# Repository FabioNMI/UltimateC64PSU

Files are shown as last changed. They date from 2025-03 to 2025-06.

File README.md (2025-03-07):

Welcome to the Ultimate Commodore 64 Power Supply!

This circuit is designed to power a Commodore 64 computer without the use of bulky transformers and by generating pseudo-AC (9Vrms) and 5Vdc to power the machine.

Please use it at your own risk, there are no guarantees that this circuit is safe as it is not certified in any way!

Link to the video in the NMI channel: https://youtu.be/_GyQUuKDc-I

There are two version that differ only in the PCB form-factor:

v7_front is the format featured in my video (power output in the front)

v8_back is a different layout with all connections on the back

Enjoy!

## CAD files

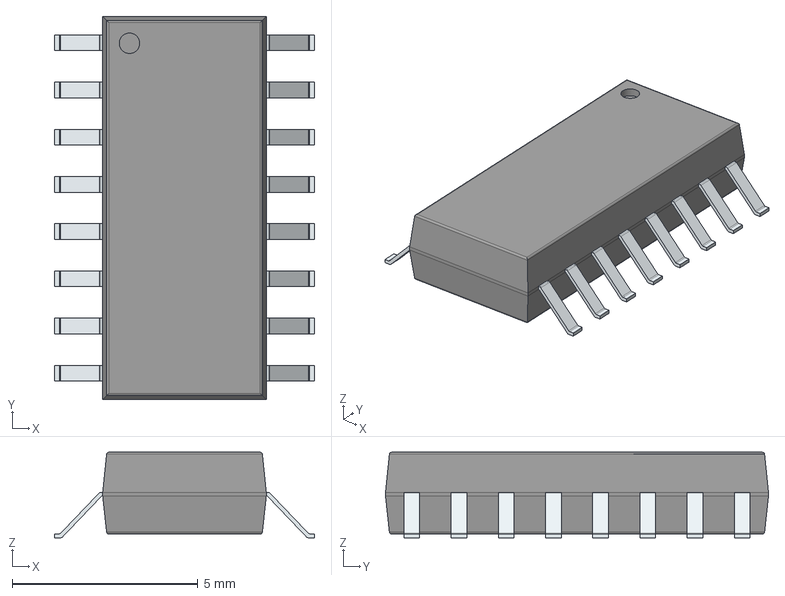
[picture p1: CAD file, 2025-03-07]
v7_front/LIB_PS2801C-4-F3-A/PS2801C-4-F3-A/3D/PS2801C-4-F3-A.stp
7.00 x 10.3 x 2.30 mm
PinsArrayLR

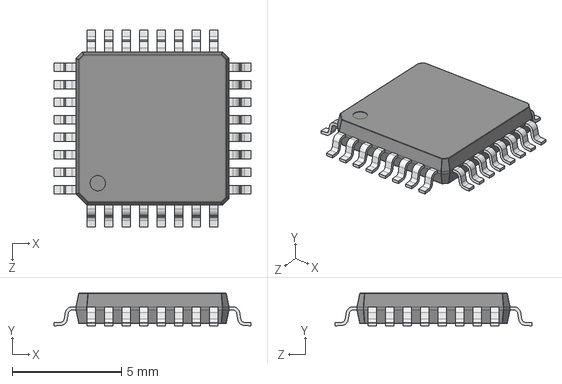
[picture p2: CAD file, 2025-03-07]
v7_front/LIB_R7FA0E1073CFJ#AA0/R7FA0E1073CFJ#AA0/3D/R7FA0E1073CFJ#AA0.stp
9.00 x 1.50 x 9.00 mm

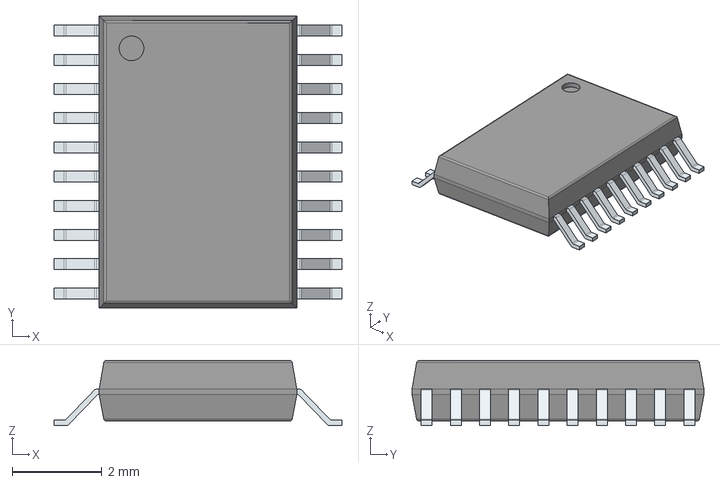
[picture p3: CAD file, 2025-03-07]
v7_front/LIB_R7FA0E1073CSC#CA0/R7FA0E1073CSC#CA0/3D/R7FA0E1073CSC#CA0.stp
6.40 x 6.50 x 1.45 mm
PinsArrayLR

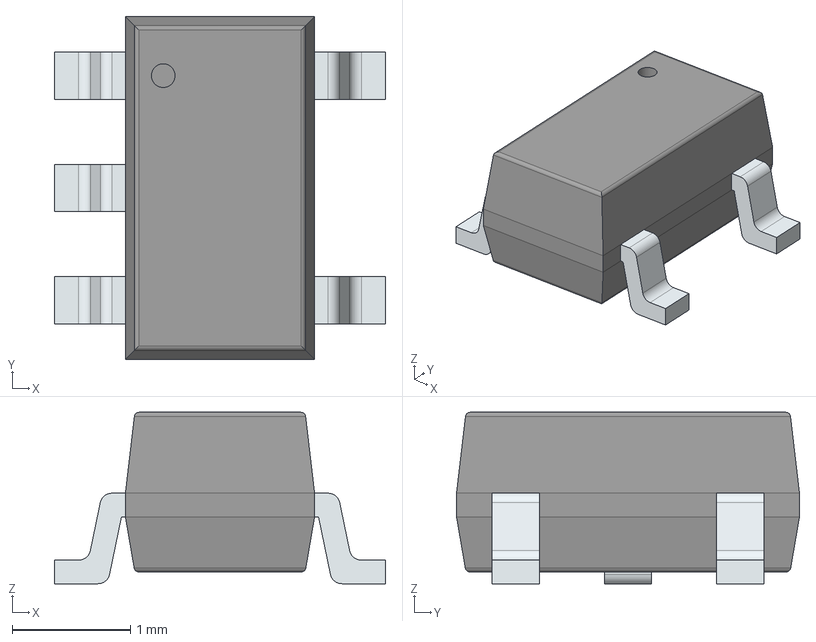
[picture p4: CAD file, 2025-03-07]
v7_front/LIB_ISL28005FH20Z-T7/ISL28005FH20Z-T7/3D/ISL28005FH20Z-T7.stp
2.80 x 2.90 x 1.45 mm
PinsArrayL
PinsArrayR

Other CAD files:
v7_front/LIB_ISL28005FH20Z-T7/ISL28005FH20Z-T7/Allegro/sot95p280x145-5n.psm
v7_front/LIB_ISL28005FH20Z-T7/ISL28005FH20Z-T7/DEHDL/isl28005fh20z_t7/chips/chips.prt
v7_front/LIB_PS2801C-4-F3-A/PS2801C-4-F3-A/Allegro/soic127p700x230-16n.psm
v7_front/LIB_PS2801C-4-F3-A/PS2801C-4-F3-A/DEHDL/ps2801c_4_f3_a/chips/chips.prt
v7_front/LIB_R7FA0E1073CFJ#AA0/R7FA0E1073CFJ#AA0/Allegro/qfp80p900x900x170-32n.psm
v7_front/LIB_R7FA0E1073CFJ#AA0/R7FA0E1073CFJ#AA0/DEHDL/r7fa0e1073cfj#aa0/chips/chips.prt
v7_front/LIB_R7FA0E1073CSC#CA0/R7FA0E1073CSC#CA0/Allegro/sop65p640x145-20n.psm
v7_front/LIB_R7FA0E1073CSC#CA0/R7FA0E1073CSC#CA0/DEHDL/r7fa0e1073csc#ca0/chips/chips.prt
v8_back/LIB_ISL28005FH20Z-T7/ISL28005FH20Z-T7/Allegro/sot95p280x145-5n.psm
v8_back/LIB_ISL28005FH20Z-T7/ISL28005FH20Z-T7/DEHDL/isl28005fh20z_t7/chips/chips.prt
v8_back/LIB_PS2801C-4-F3-A/PS2801C-4-F3-A/Allegro/soic127p700x230-16n.psm
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

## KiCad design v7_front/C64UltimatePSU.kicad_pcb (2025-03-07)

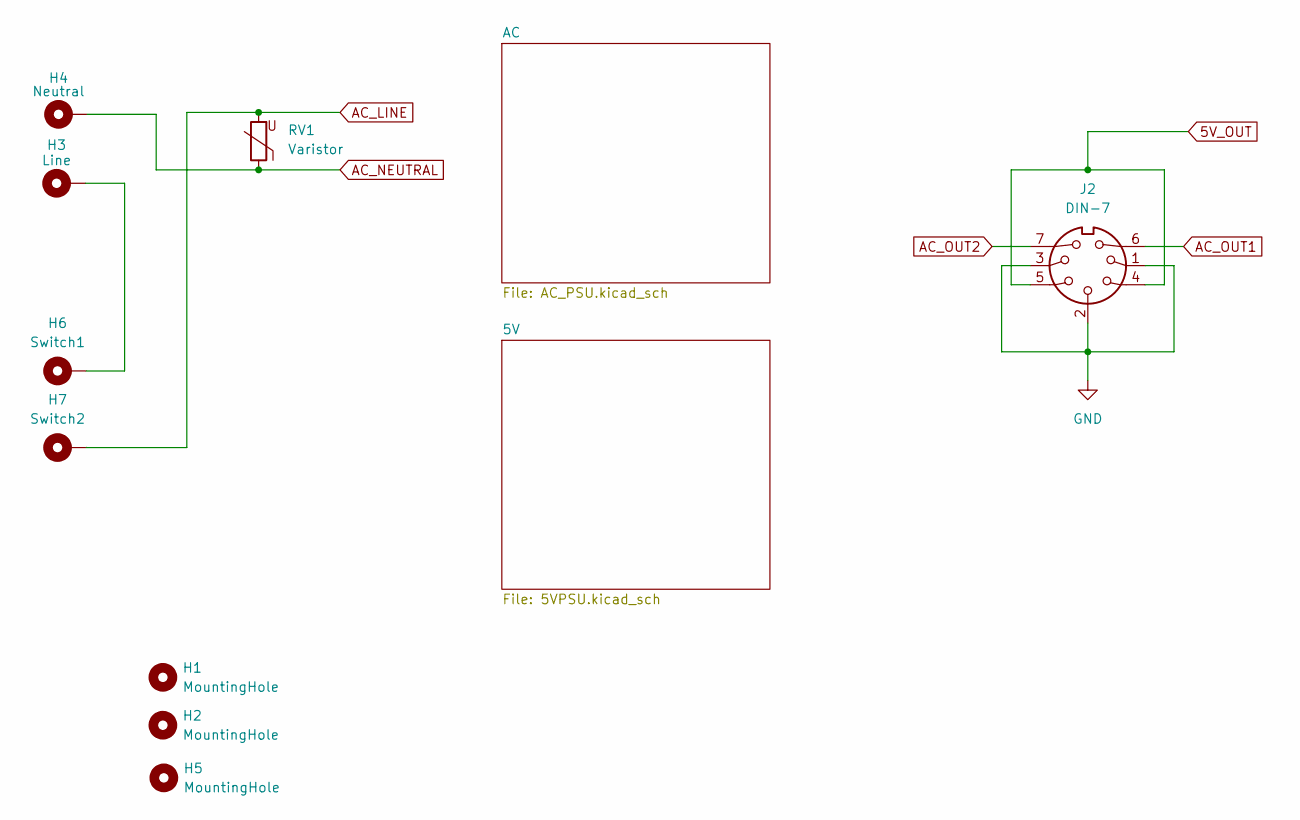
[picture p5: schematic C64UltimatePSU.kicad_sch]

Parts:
H1, H2, H5: MountingHole; MountingHole_3.5mm
H3: Line; MountingHole_2.5mm_Pad
H4: Neutral; MountingHole_2.5mm_Pad
H6: Switch1; MountingHole_2.5mm_Pad
H7: Switch2; MountingHole_2.5mm_Pad
J2: DIN-7; POWER_CON_DIN7
RV1: Varistor; RV_Disc_D7mm_W4mm_P5mm

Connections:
5V_OUT: J2.4, J2.5; also elsewhere on the board
AC_LINE: H7.1, RV1.2; also elsewhere on the board
AC_NEUTRAL: H4.1, RV1.1; also elsewhere on the board
AC_OUT1: J2.6; also elsewhere on the board
AC_OUT2: J2.7; also elsewhere on the board
GND: J2.1, J2.2, J2.3; also elsewhere on the board
unnamed: H3.1, H6.1

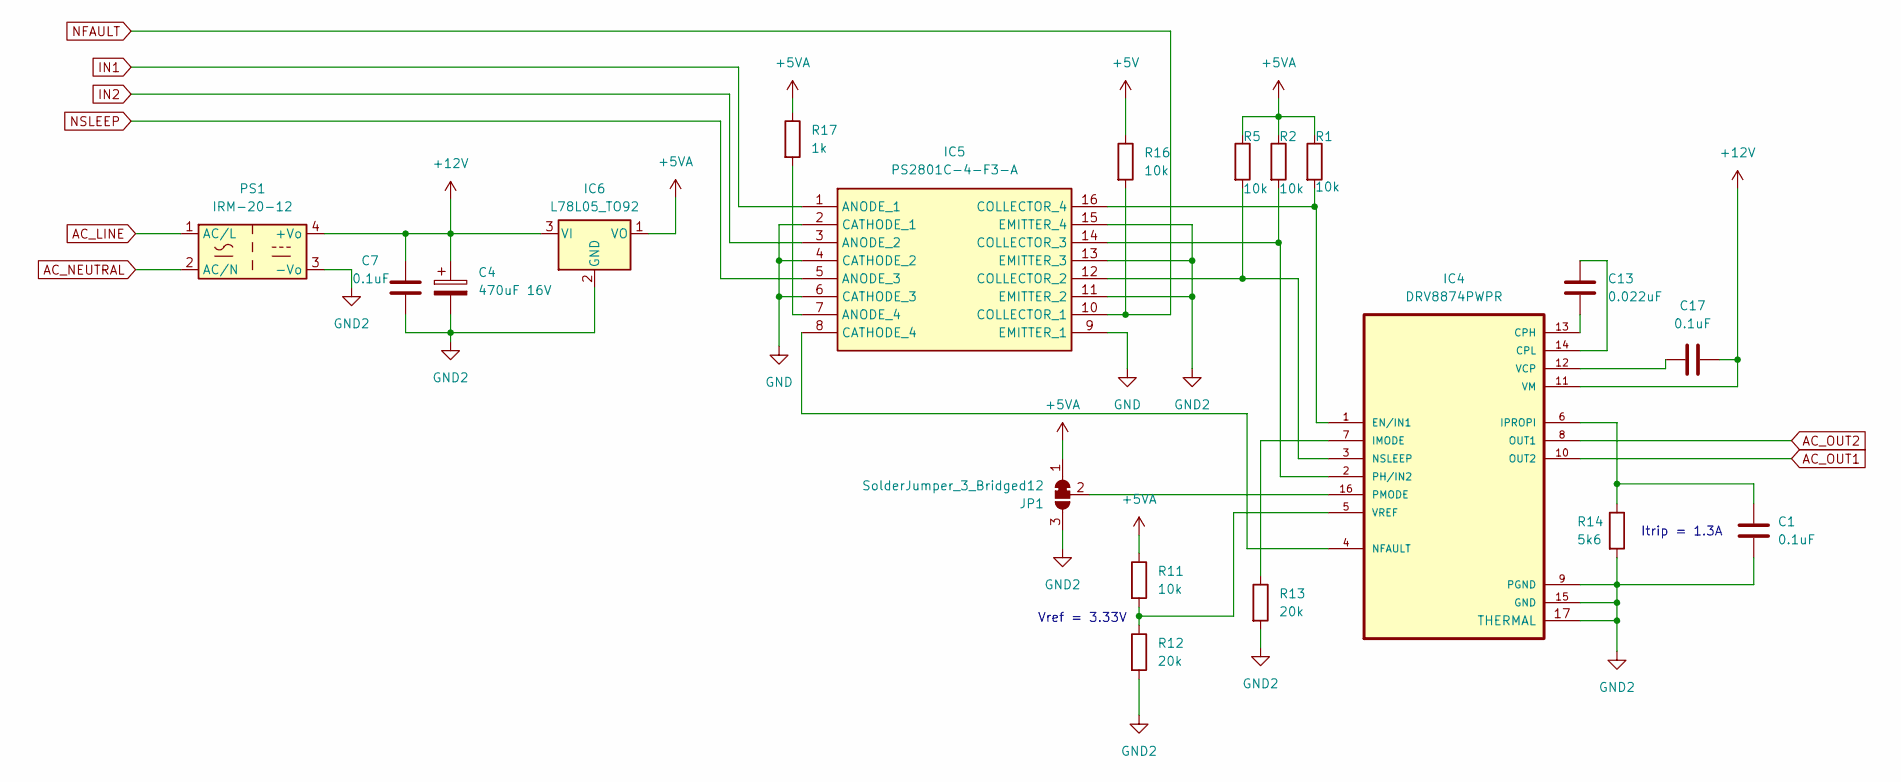
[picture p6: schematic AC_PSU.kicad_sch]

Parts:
C1, C7, C17: 0.1uF; C_0805_2012Metric_Pad1.18x1.45mm_HandSolder
C4: 470uF 16V; CP_Radial_D6.3mm_P2.50mm
C13: 0.022uF; C_0805_2012Metric_Pad1.18x1.45mm_HandSolder
IC4: DRV8874PWPR; SOP65P640X120-17N
IC5: PS2801C-4-F3-A; SOIC-16_4.55x10.3mm_P1.27mm; Manufacturer_Part_Number PS2801C-4-F3-A
IC6: L78L05_TO92; TO-92_Inline
JP1: SolderJumper_3_Bridged12; SolderJumper-3_P1.3mm_Bridged12_Pad1.0x1.5mm_NumberLabels
PS1: IRM-20-12; Converter_ACDC_MeanWell_IRM-20-xx_THT
R1, R2, R5, R11, R16: 10k; R_0805_2012Metric_Pad1.20x1.40mm_HandSolder
R12, R13: 20k; R_0805_2012Metric_Pad1.20x1.40mm_HandSolder
R14: 5k6; R_0805_2012Metric_Pad1.20x1.40mm_HandSolder
R17: 1k; R_0805_2012Metric_Pad1.20x1.40mm_HandSolder

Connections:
+5V: R16.1; also elsewhere on the board
+5VA: IC6.1 (VO), JP1.1 (A), R1.1, R2.1, R5.1, R11.1, R17.1
+12V: C4.1, C7.2, C17.2, IC4.11 (VM), IC6.3 (VI), PS1.4 (+Vo)
AC_LINE: PS1.1 (AC/L); also elsewhere on the board
AC_NEUTRAL: PS1.2 (AC/N); also elsewhere on the board
AC_OUT1: IC4.10 (OUT2); also elsewhere on the board
AC_OUT2: IC4.8 (OUT1); also elsewhere on the board
GND: IC5.2 (CATHODE_1), IC5.4 (CATHODE_2), IC5.6 (CATHODE_3), IC5.9 (EMITTER_1); also elsewhere on the board
GND2: C1.1, C4.2, C7.1, IC4.9 (PGND), IC4.15 (GND), IC4.17 (THERMAL), IC5.11 (EMITTER_2), IC5.13 (EMITTER_3), IC5.15 (EMITTER_4), IC6.2 (GND), JP1.3 (B), PS1.3 (-Vo), R12.2, R13.2, R14.2
IN1: IC5.1 (ANODE_1); also elsewhere on the board
IN2: IC5.3 (ANODE_2); also elsewhere on the board
NFAULT: IC5.10 (COLLECTOR_1), R16.2; also elsewhere on the board
NSLEEP: IC5.5 (ANODE_3); also elsewhere on the board
unnamed: C13.2, IC4.13 (CPH)
unnamed: C13.1, IC4.14 (CPL)
unnamed: IC4.1 (EN/IN1), IC5.16 (COLLECTOR_4), R1.2
unnamed: IC4.7 (IMODE), R13.1
unnamed: C1.2, IC4.6 (IPROPI), R14.1
unnamed: IC4.4 (NFAULT), IC5.8 (CATHODE_4)
unnamed: IC4.3 (NSLEEP), IC5.12 (COLLECTOR_2), R5.2
unnamed: IC4.2 (PH/IN2), IC5.14 (COLLECTOR_3), R2.2
unnamed: IC4.16 (PMODE), JP1.2 (C)
unnamed: C17.1, IC4.12 (VCP)
unnamed: IC4.5 (VREF), R11.2, R12.1
unnamed: IC5.7 (ANODE_4), R17.2

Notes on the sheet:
Vref = 3.33V
Itrip = 1.3A

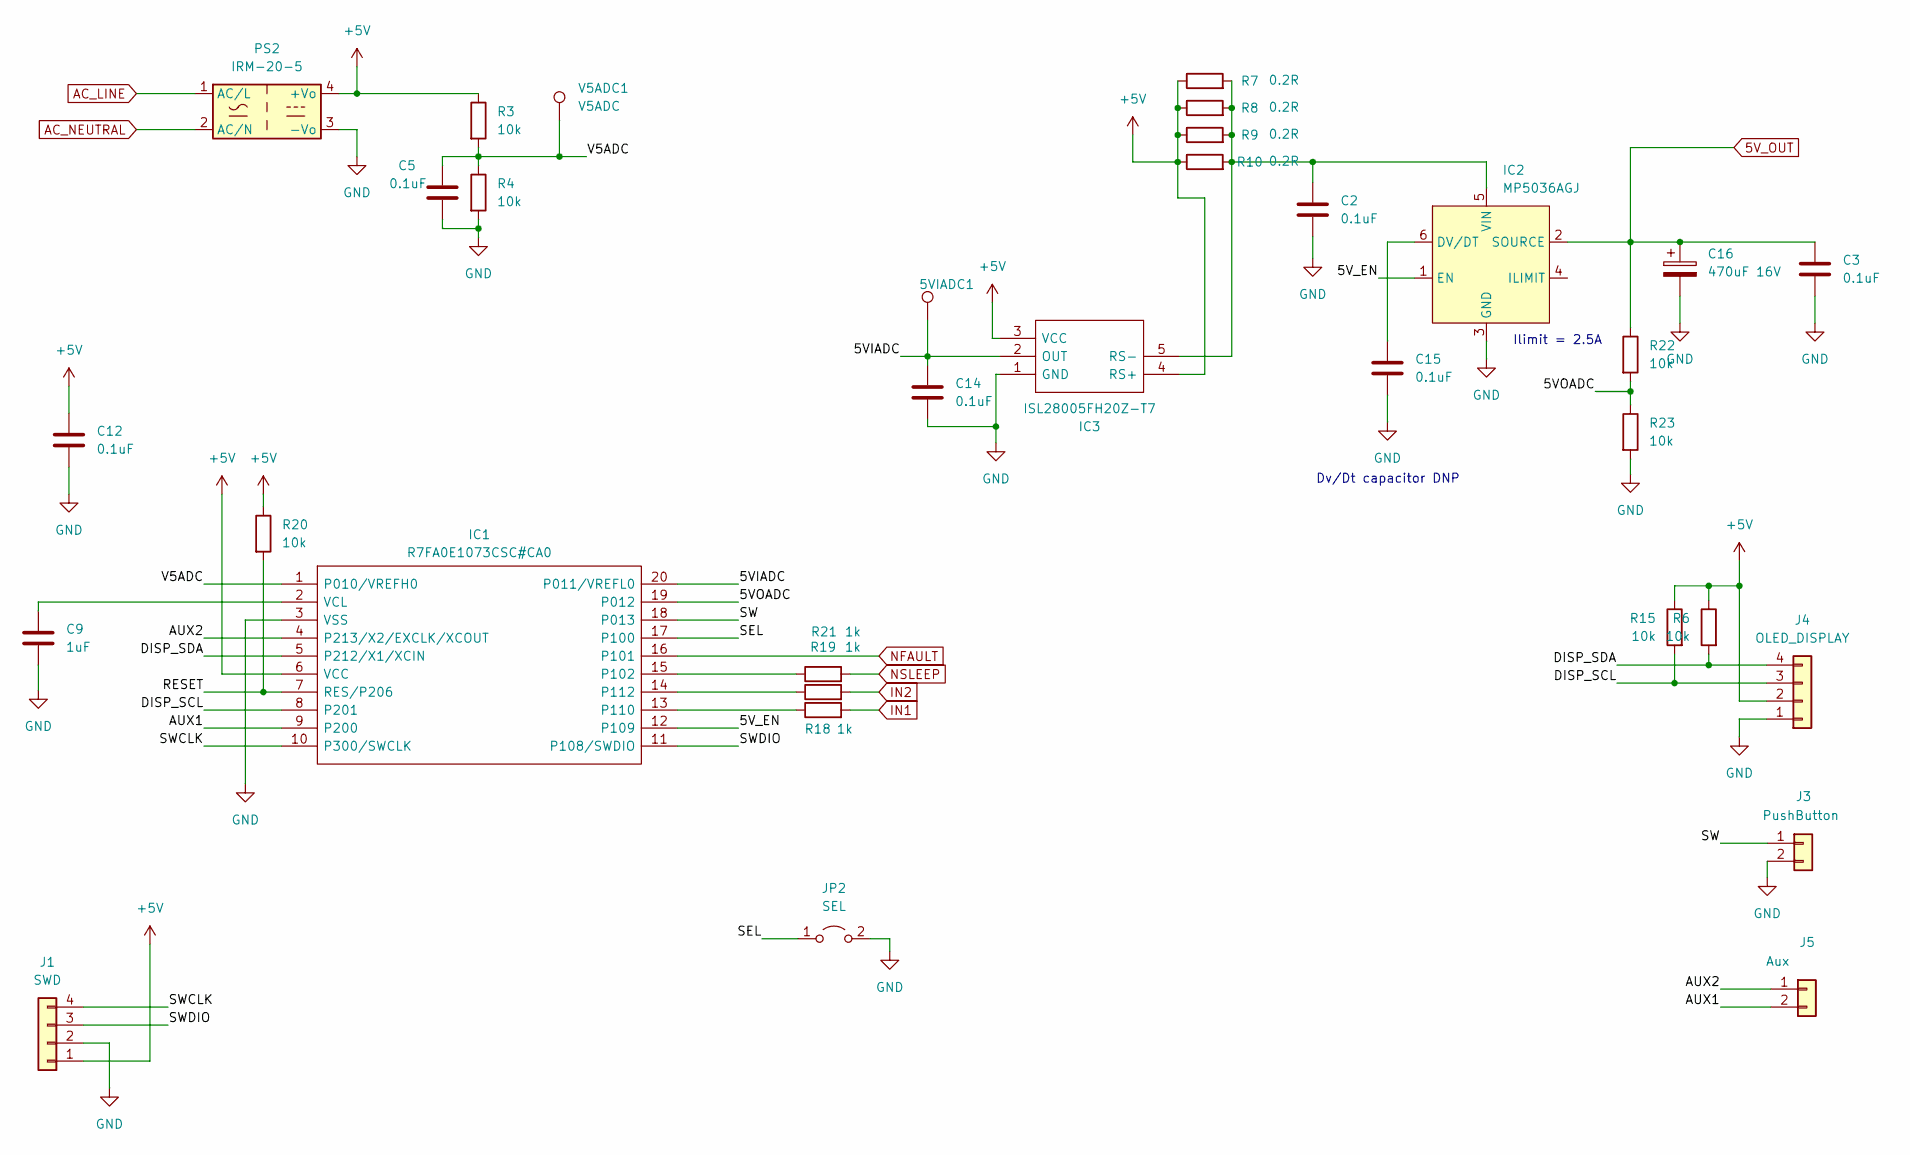
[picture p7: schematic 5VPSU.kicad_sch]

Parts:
5VIADC1: TestPoint_Pad_D1.0mm
C2, C3, C5, C12, C14, C15: 0.1uF; C_0805_2012Metric_Pad1.18x1.45mm_HandSolder
C9: 1uF; C_0805_2012Metric_Pad1.18x1.45mm_HandSolder
C16: 470uF 16V; CP_Radial_D6.3mm_P2.50mm
IC1: R7FA0E1073CSC#CA0; SSOP-20_4.4x6.5mm_P0.65mm; Manufacturer_Part_Number R7FA0E1073CSC#CA0
IC2: MP5036AGJ; SOT-23-6_Handsoldering
IC3: ISL28005FH20Z-T7; SOT-23-5_HandSoldering; Manufacturer_Part_Number ISL28005FH20Z-T7; Mouser Part Number 968-ISL28005FH20Z-T7
J1: SWD; PinHeader_1x04_P2.54mm_Vertical
J3: PushButton; PinHeader_1x02_P2.54mm_Vertical
J4: OLED_DISPLAY; PinHeader_1x04_P2.54mm_Vertical
J5: Aux; PinHeader_1x02_P2.54mm_Vertical
JP2: SEL; PinHeader_1x02_P2.54mm_Vertical
PS2: IRM-20-5; Converter_ACDC_MeanWell_IRM-20-xx_THT
R3, R4, R6, R15, R20, R22, R23: 10k; R_0805_2012Metric_Pad1.20x1.40mm_HandSolder
R7, R8, R9, R10: 0.2R; R_1206_3216Metric_Pad1.30x1.75mm_HandSolder
R18, R19, R21: 1k; R_0805_2012Metric_Pad1.20x1.40mm_HandSolder
V5ADC1: V5ADC; TestPoint_Pad_D1.0mm

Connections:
5V_OUT: C3.2, C16.1, IC2.2 (SOURCE), R22.1; also elsewhere on the board
+5V: C12.2, IC1.6 (VCC), IC3.3 (VCC), IC3.4 (RS+), J1.1, J4.2, PS2.4 (+Vo), R3.1, R6.1, R7.1, R8.1, R9.1, R10.1, R15.1, R20.1; also elsewhere on the board
/5V/5VIADC: 5VIADC1.1, C14.2, IC1.20 (P011/VREFL0), IC3.2 (OUT)
/5V/5VOADC: IC1.19 (P012), R22.2, R23.1
/5V/5V_EN: IC1.12 (P109), IC2.1 (EN)
/5V/AUX1: IC1.9 (P200), J5.2
/5V/AUX2: IC1.4 (P213/X2/EXCLK/XCOUT), J5.1
/5V/DISP_SCL: IC1.8 (P201), J4.3, R15.2
/5V/DISP_SDA: IC1.5 (P212/X1/XCIN), J4.4, R6.2
/5V/RESET: IC1.7 (RES/P206), R20.2
/5V/SEL: IC1.17 (P100), JP2.1 (A)
/5V/SW: IC1.18 (P013), J3.1
/5V/SWCLK: IC1.10 (P300/SWCLK), J1.4
/5V/SWDIO: IC1.11 (P108/SWDIO), J1.3
/5V/V5ADC: C5.2, IC1.1 (P010/VREFH0), R3.2, R4.1, V5ADC1.1
AC_LINE: PS2.1 (AC/L); also elsewhere on the board
AC_NEUTRAL: PS2.2 (AC/N); also elsewhere on the board
GND: C2.1, C3.1, C5.1, C9.1, C12.1, C14.1, C15.1, C16.2, IC1.3 (VSS), IC2.3 (GND), IC3.1 (GND), J1.2, J3.2, J4.1, JP2.2 (B), PS2.3 (-Vo), R4.2, R23.2; also elsewhere on the board
IN1: R18.2; also elsewhere on the board
IN2: R19.2; also elsewhere on the board
NFAULT: IC1.16 (P101); also elsewhere on the board
NSLEEP: R21.2; also elsewhere on the board
unnamed: IC1.15 (P102), R21.1
unnamed: IC1.13 (P110), R18.1
unnamed: IC1.14 (P112), R19.1
unnamed: C9.2, IC1.2 (VCL)
unnamed: C15.2, IC2.6 (DV/DT)
unnamed: C2.2, IC2.5 (VIN), IC3.5 (RS-), R7.2, R8.2, R9.2, R10.2

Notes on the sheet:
Dv/Dt capacitor DNP
Ilimit = 2.5A

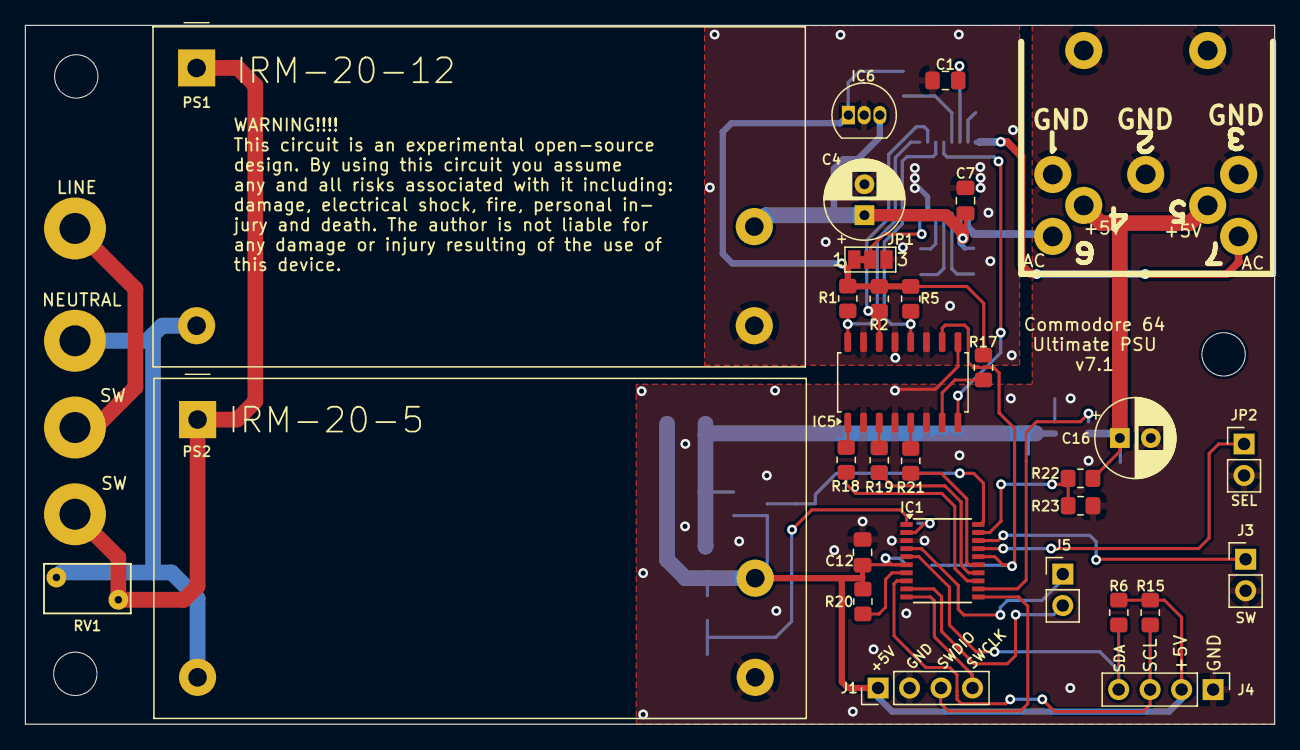
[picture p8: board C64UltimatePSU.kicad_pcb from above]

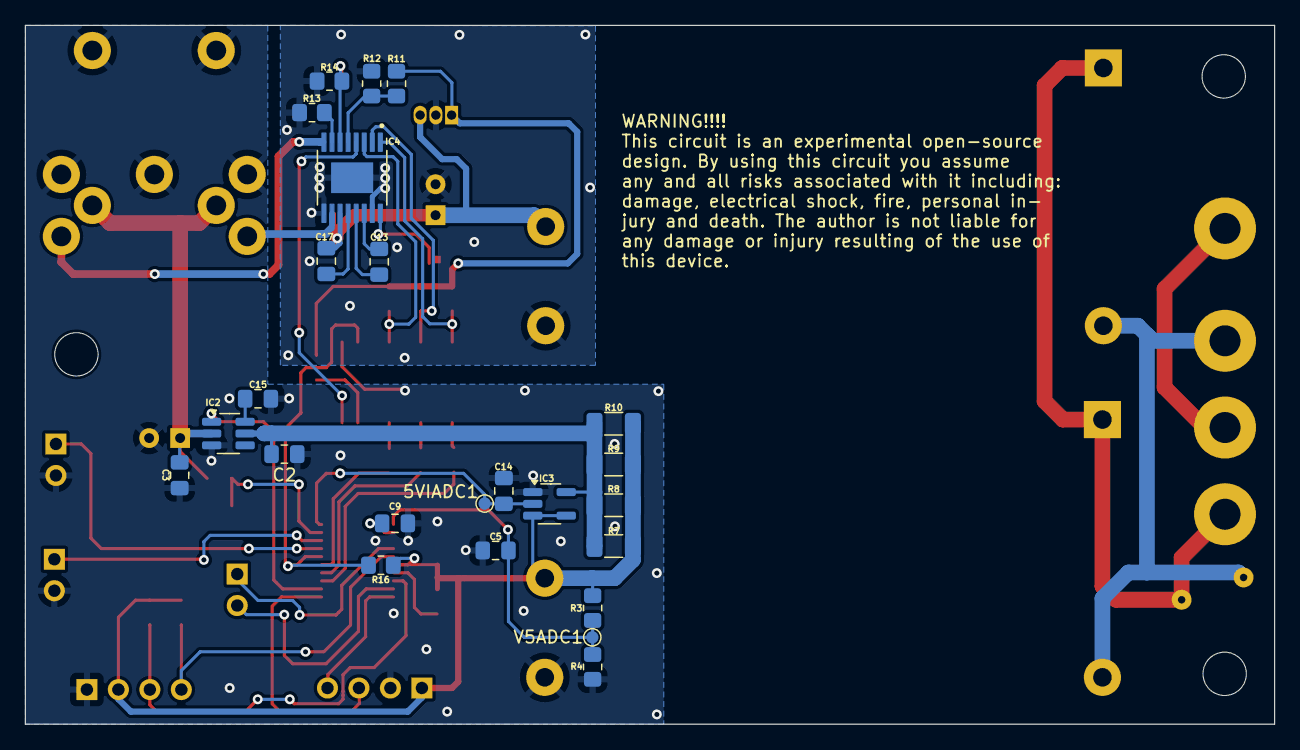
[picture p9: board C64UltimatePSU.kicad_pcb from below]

Board: 2 copper layers, 100.8 x 56.4 mm, 61 parts (24 on the bottom side), 46 nets.

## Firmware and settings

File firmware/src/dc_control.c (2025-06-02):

/*
 * dc_control.c
 *
 *  Created on: Jan. 25, 2025
 *      Author: fabiop
 */

#include <dc_control.h>
#include <hal_data.h>
#include <utils.h>

#define ADC_V               ADC_CHANNEL_0
#define ADC_I               ADC_CHANNEL_1
#define ADC_VO              ADC_CHANNEL_4

uint16_t v5raw, i5raw;
uint32_t v5avg, i5avg;
psu_state_t dc_state;
uint32_t analog_sample_timer;
uint8_t adc_num_samples;

void adc_init(void);
uint16_t adc_get_reading(adc_channel_t in);
void enable_dc_power(bool state);
void read_analog_data(void);

void adc_init(void) {
    R_ADC_D_Open(&g_adc0_ctrl, &g_adc0_cfg);
    adc_num_samples = 0;
}

uint16_t adc_get_reading(adc_channel_t adc_channel) {
    uint16_t result = 0;
    //R_ADC_D->ADS = (uint8_t)adc_channel;
    R_ADC_D_ScanCfg(&g_adc0_ctrl, &adc_channel);
    R_ADC_D_ScanStart (&g_adc0_ctrl);
    // Wait for the ADC conversion to complete
    while (R_ADC_D->ADM0_b.ADCS);
    R_ADC_D_Read(&g_adc0_ctrl, adc_channel, &result);
    return result;
}

void enable_dc_power(bool state) {
    R_IOPORT_PinWrite(&g_ioport_ctrl, PIN_5V_EN, state);
}

void read_analog_data(void) {
    if (utils_get_time() > analog_sample_timer + SMP_INT) {
        if (analog_sample_timer == 0) {
            v5avg = adc_get_reading(ADC_V) << ADC_AVERAGING;
            i5avg = adc_get_reading(ADC_I) << ADC_AVERAGING;
        } else {
            v5avg += adc_get_reading(ADC_V) - (v5avg >> ADC_AVERAGING);
            i5avg += adc_get_reading(ADC_I) - (i5avg >> ADC_AVERAGING);
            v5raw = v5avg >> ADC_AVERAGING;
            i5raw = i5avg >> ADC_AVERAGING;
        }
        analog_sample_timer = utils_get_time();
        if (adc_num_samples<100) adc_num_samples++;
    }
}

// In this function we check the voltage and current of the DC section
psu_state_t dc_check_status(void) {
    if (adc_num_samples < 10) return STATE_OFF;
    if (v5raw > V5_MAX_RAW) {
        return STATE_OVERVOLTAGE;
    } else if (i5raw > I5_MAX_RAW) {
        return STATE_OVERCURRENT;
    } else if (v5raw < V5_MIN_RAW) {
        return STATE_UNDERVOLTAGE;
    } else if (i5raw < I5_MIN) {
        return STATE_OFF;
    }
    return STATE_ON;
}

psu_state_t dc_control_fsm(psu_state_t new_state) {
    read_analog_data();
    switch (dc_state) {
        case STATE_INIT:    // Just initialize ADC and move on
            adc_init();
            dc_state = STATE_ON;
            break;
        case STATE_OFF:     // DC is always on!
            dc_state = STATE_ON;
            break;
        case STATE_ON:      // DC power is on, monitor parameters and check if we should power off due to a fault
            enable_dc_power(true);
            psu_state_t status = dc_check_status();
            if (status != STATE_ON && status != STATE_OFF) {
                enable_dc_power(false);
                dc_state = STATE_FAULT;
            }
            break;
        default:
            if (new_state == STATE_ON) {
                dc_state = STATE_ON;
            }
            enable_dc_power(false);
            break;
    }
    return dc_state;
}

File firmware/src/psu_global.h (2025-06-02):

/*
 * c64_psu.h
 *
 *  Created on: Jan. 25, 2025
 *      Author: fabiop
 */

#ifndef PSU_GLOBAL_H_
#define PSU_GLOBAL_H_

#include <hal_data.h>

#define AC_FREQUENCY        (60)      // AC output frequency in Hz
#define AC_DUTY_CYCLE       (75)      // The duty-cycle to use on the pseudo-AC waveform

#define SPLASH_X            (15)
#define SPLASH_Y            (5)
#define V_PX                (5)
#define V_PY                (8)
#define I_PX                (60)
#define I_PY                (8)
#define P_PX                (25)
#define P_PY                (29)
#define AC_ERR_PX           (80)
#define DC_ERR_PX           (10)
#define ERR_PY              (20)
#define BYE_PX              (30)
#define BYE_PY              (23)
#define GUI_UPDATE_TIME     (250LU)   // milliseconds
#define GUI_SPLASH_TIME     (3000LU)  // milliseconds
#define GUI_SAVER_TIME      (5000LU)  // milliseconds

#define V5_MAX              (510LU)   // Maximum voltage allowed on the 5V DC bus (multiplied by 100)
#define V5_MIN              (485LU)   // Minimum voltage allowed on the 5V DC bus (multiplied by 100)
#define I5_MAX              (2000LU)  // Maximum current allowed on the 5V rail
#define AUTO_OFF_TIME       (5000LU)  // Time for automatically turning off (milliseconds)
#define I5_MIN              (100LU)   // Minimum current (in mA) on 5V bus to turn off AC output and switch off PSU
#define SMP_INT             (10)      // perform analog readings at this interval (ms)
#define DRV8874_FLT_DELAY   (250LU)   // Delay before checking fault status (ms)
#define DRV8874_RETRY       (200LU)   // Retry time in ms on a DRV8874fault
#define R3                  (10000LU) // upper V5 resistor divider
#define R4                  (10000LU) // lower V5 resistor divider
#define PRECISION_FACTOR    (100LU)
#define ADC_MAX_COUNT       (4095)    // use 4095 -> 12 bits ADCs!
#define ADC_MAX_VOLTAGE     (500)     // 500 = 5.00V
#define ADC_AVERAGING       (3)       // 2 to the power of this number (ie 2^3 -> average is 8 samples)
#define V5_DIVIDER          (((R3+R4)*PRECISION_FACTOR)/R4) // this is multiplied by the precision factor in order to keep some precision
#define I5_DIVIDER          ((uint32_t)(1.00*PRECISION_FACTOR))
#define V5_MAX_RAW          ((((V5_MAX * PRECISION_FACTOR)/V5_DIVIDER)*ADC_MAX_COUNT)/ADC_MAX_VOLTAGE)
#define V5_MIN_RAW          ((((V5_MIN * PRECISION_FACTOR)/V5_DIVIDER)*ADC_MAX_COUNT)/ADC_MAX_VOLTAGE)
#define I5_MAX_RAW          ((((I5_MAX * PRECISION_FACTOR)/I5_DIVIDER/10)*ADC_MAX_COUNT)/ADC_MAX_VOLTAGE)
#define I5_MIN_RAW          ((((I5_MIN * PRECISION_FACTOR)/I5_DIVIDER/10)*ADC_MAX_COUNT)/ADC_MAX_VOLTAGE)

typedef enum {
  ERR_NONE,
  ERR_V5_HIGH,
  ERR_V5_LOW,
  ERR_V5_CURRENT,
  ERR_V12_FAULT
} error_code_t;

typedef enum {
    STATE_INIT,
    STATE_OFF,
    STATE_ON,
    STATE_FAULT,
    STATE_OVERVOLTAGE,
    STATE_UNDERVOLTAGE,
    STATE_OVERCURRENT,
    STATE_UNDERCURRENT,
    STATE_NONE
} psu_state_t;

#endif /* PSU_GLOBAL_H_ */

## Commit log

2025-03-07 Moved repository
    [5VPSU.kicad_sch, AC_PSU.kicad_sch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]
2025-03-07 Moved to version folder
    [5VPSU.kicad_sch, AC_PSU.kicad_sch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]
2025-03-07 Updated folder names, added v8
    [5VPSU.kicad_sch, AC_PSU.kicad_sch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]
